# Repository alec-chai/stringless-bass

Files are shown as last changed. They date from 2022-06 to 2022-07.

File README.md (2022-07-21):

# Stringless Bass Project

Lawrence Wilen, Alec Chai, Marley Macarewich

## Summary

This repository contains all of the code, files, and documentation that are necessary for reproducing the stringless basses created during the Summer 2022 Projects to Products CEID Fellowship. Each folder contains necessary files for that iteration.

## Contents

- Working Bass Code
  - Code is labelled using semantic versioning (x.y.z), eg. version 0.2.1. Each y value represents a different physical version of the bass, while an updated z value represents an updated version of the code. For example, both the code labelled v0.4.0 and v0.4.1 would be compatible with the physical bass number v0.4, but v0.4.1 is the more recent version of the code. 
- Deprecated
  - This code is old, outdated, or incompatible with physical designs. It is included here just for documentation, but is not intended to be used seriously for any of the basses.
- Physical Design Files
  - Solidworks, CorelDraw, and exported DXF files necessary for laser cutting the bass prototypes.
- Softpot Calibration Files
  - This folder contains the code and excel sheets necessary to linearize the calibration of the softpots on the basses.
- Pre-alpha
  - This folder contains code that is under construction and uploaded for the purposes of testing.

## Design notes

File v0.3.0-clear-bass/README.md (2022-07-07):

# Version 3: The Brockstar

## Summary

This is the code for the clear bass created from acrylic that was originally intended to be "The Brockstar." This features the large clear "bass-like" cutout.

This is the iteration that was intended to be given to Dean Brock as "The Brockstar", but we delivered Version 2 to him as we had too many technical difficulties to troubleshoot on our actual "Brockstar" iteration.

Code was updated to be a little more legible, however most changes in this code were just deleting extraneous unused variables/code and renaming a number of variables.

## Notable Hardware

- Teensy 3.2
- BNO-055
- Powered by either DC power supply or USB power
- Ethernet connection between bow and bass body

## Changes

- Using the Neopixel library to control LEDs on the entire bow and entire bass body

- Body is cut out of four different layers. From top to bottom: 1/4 inch, 1/4 inch (hollow), 1/2 inch (hollow), 1/4 inch

  - Cavity inside of the bass body is now 3/4 in thick.

## Notes

- The FastLED library has worse performance than the Neopixel library for updating the colors of the neopixel strips in terms of latency and in bugs. In this version of the code, all LED changes are done through the neopixel library.

- This iteration's BNO-055 did not function at all without 4.7 kohm pullup resistors connecting the SDA/SCL lines to ground. Once the pullup resistors were added, the BNO functions quite well. 

- On this iteration, the orientation of the BNO was flipped 180 degrees about the Y-axis, leading to issues with the quaternion code that converts to Euler angles. This was remedied by flipping the sign of the q0prime and q3prime quaternions as:

  - `q0prime = -quat.w();`
  - `q3prime = -quat.z();`

  Another suitable solution was to flip the signs of q1 and q2. 

- The pluck velocity code also needed to change in sign, so the code was updated to ` plucksig = -gyro.z();`

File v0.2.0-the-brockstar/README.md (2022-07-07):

# Version 2: Clear Bass w/ Code Rewrite

## Summary

This is the code for the clear bass created from acrylic. This features the large clear "bass-like" cutout.

This is the iteration that was given to Dean Brock as "The Brockstar", as we had to troubleshoot technical difficulties on our actual "Brockstar" iteration.

Code was updated to be a little more legible, however most changes in this code were just deleting extraneous unused variables/code and renaming a number of variables.

## Notable Hardware

- Teensy 3.2
- BNO-055
- Powered by either DC power supply or USB power
- Ethernet connection between bow and bass body

## Changes

- Added ethernet jack to connect the bass body to the bow
- Added DC power supply
- Cut out of acrylic
- Added Neopixel LEDs to the entire bow and entire bass body
- Renamed L1/L2/L3 to L_nut, L_bridge, and L_between to improve clarity
- LEDs are running using the FastLED library
- Bug fix: Changed the logic of if statements that led to a bowed note being played while in the plucking position.

## Notes

The FastLED library has worse performance than the Neopixel library for updating the colors of the neopixel strips in terms of latency and in bugs. This code is essentially a worse version of the v3-brockstar code, but it is uploaded just for proper documentation.

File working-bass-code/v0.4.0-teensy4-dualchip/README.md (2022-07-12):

# Version 4: unnamed so far

## Summary

This is the code for the 3rd iteration of a clear bass using Teensy 4.0.

Code in this version supports the use of either a FXO-FXA or the BNO by uncommenting certain lines.

## Notable Hardware

- Teensy 4.0 w/ PT8211
- BNO-055 OR FXO-FXA
- Powered by USB power
- Ethernet connection between bow and bass body

## Changes

- Using the Teensy 4.0 instead of 3.2

- Added support for the FXO-FXA motion sensor in place of BNO due to chip shortage

- Body now contains a side port.

## Notes

- None yet

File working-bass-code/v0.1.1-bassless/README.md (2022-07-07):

# Version 1: Bassless

## Summary

Bassless is the copycat iteration of the original wooden basses that we were given in the summer.

Our copycat iteration, Bassless (v1), uses nearly identical code to the original bass that we were given. 

## Notable Hardware

- Teensy 3.2
- BNO-055

## Changes

None - essentially original copy of code

## Notes

This code is roughly the same as the original code, but contains different softpot calibration values and has pins A6 and A7 reversed in terms of which ones map to L1/L3 in the code.

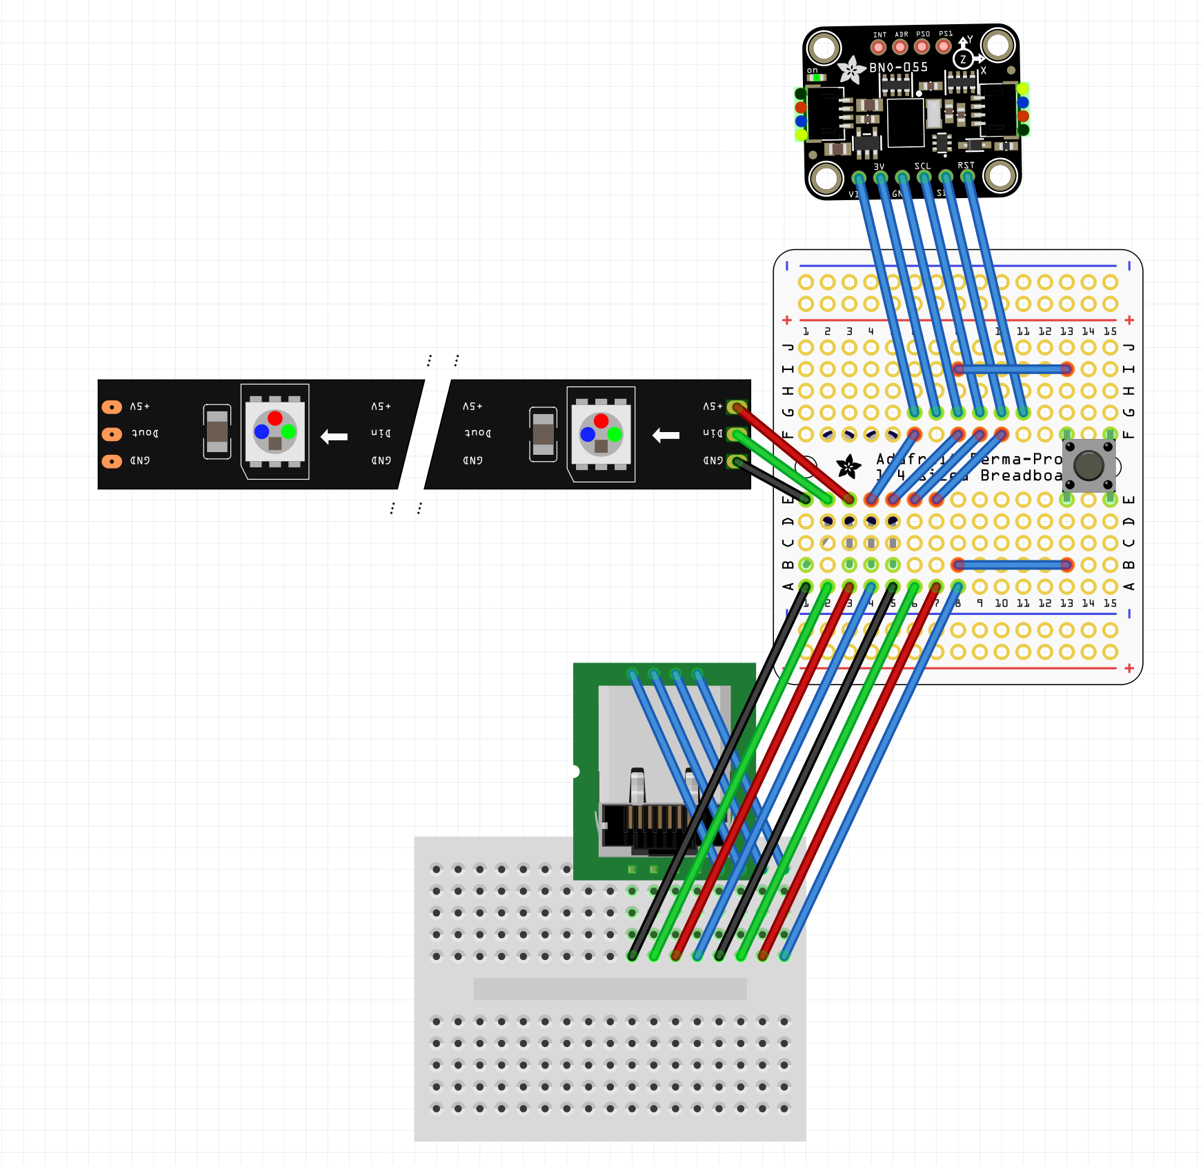
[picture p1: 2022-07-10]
v0.3.0-clear-bass/Fritzing-diagrams/bow-breadboard.png

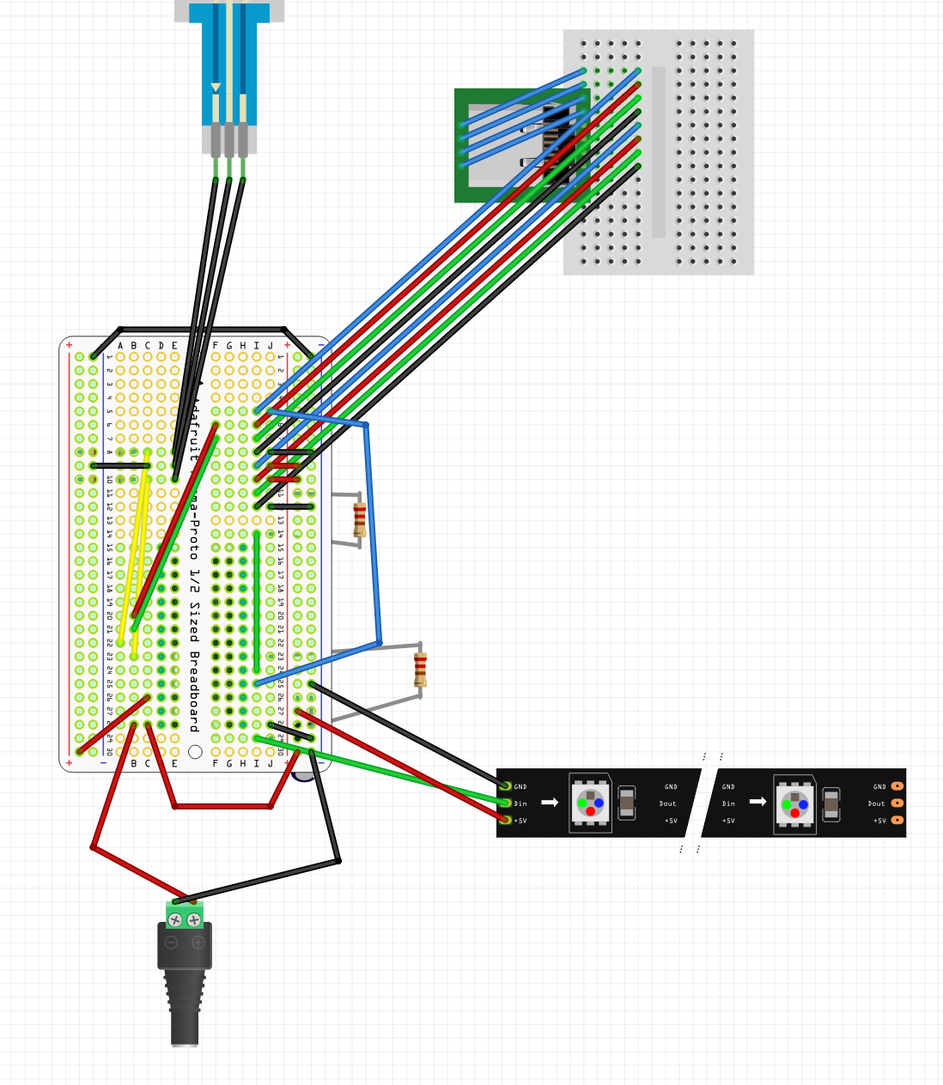
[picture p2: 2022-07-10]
v0.3.0-clear-bass/Fritzing-diagrams/body-breadboard.png

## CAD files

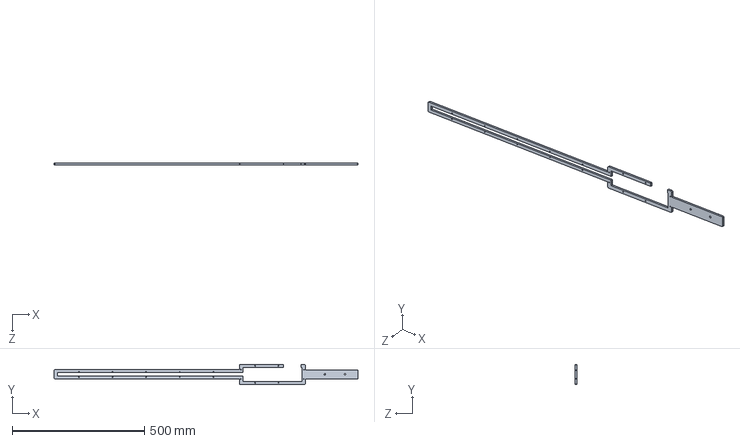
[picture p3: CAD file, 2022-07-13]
physical-design-files/BassMidLayer1.SLDPRT
1148.0 x 75.6 x 6.35 mm

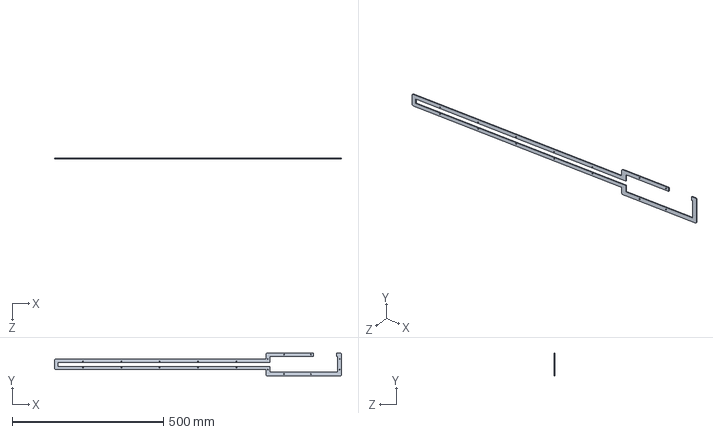
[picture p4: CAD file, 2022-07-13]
physical-design-files/BassMidLayer2.SLDPRT
949.4 x 75.6 x 2.54 mm

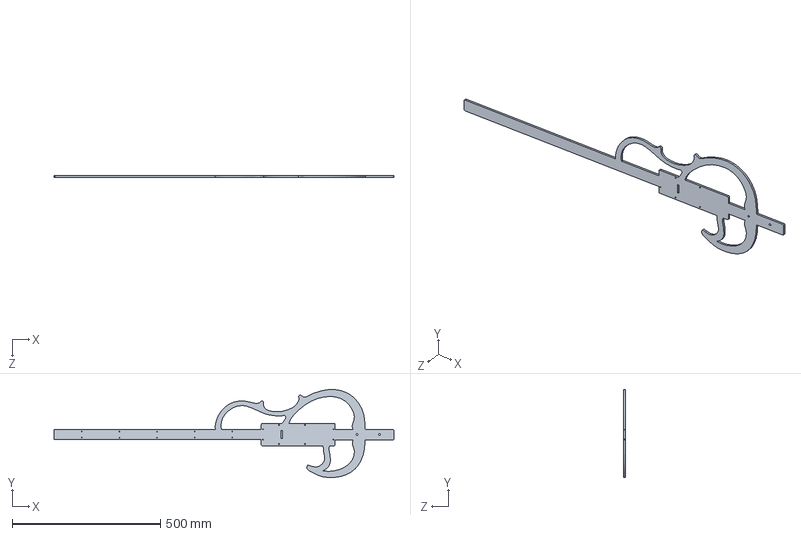
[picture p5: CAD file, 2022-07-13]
physical-design-files/BassTopLayer.SLDPRT
1148.0 x 297.1 x 6.35 mm

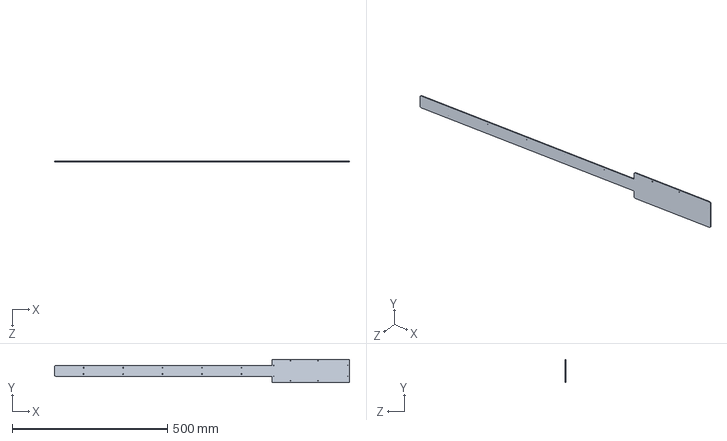
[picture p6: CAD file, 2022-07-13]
physical-design-files/BassBottomLayer.SLDPRT
949.4 x 75.6 x 2.54 mm

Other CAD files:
physical-design-files/BassBottomLayer.DXF
physical-design-files/BassMidLayer1.DXF
physical-design-files/BassMidLayer2.DXF
physical-design-files/BassTopLayer.DXF

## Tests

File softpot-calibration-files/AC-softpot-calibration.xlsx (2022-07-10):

Fret Number | Fret Relative Lstring |  |  | L_bridge softpot | Raw bridge read | Raw nut read | Linear mapping
0 | 1 | 0 | 0 | 75 | open | open | n/a
1 | 0.9438743127 | 2.30115318 | 5.844929077 | 69.15507092 | 2001.63 |  | 0.955719381
2 | 0.8908987181 | 4.473152556 | 11.36180749 | 63.63819251 | 1901.56 |  | 0.8665354259
3 | 0.8408964153 | 6.523246975 | 16.56904732 | 58.43095268 | 1829 |  | 0.8067931187
4 | 0.793700526 | 8.458278435 | 21.48402722 | 53.51597278 | 1732.88 |  | 0.7333017367
5 | 0.7491535384 | 10.28470492 | 26.12315051 | 48.87684949 | 1636.69 |  | 0.665507805
6 | 0.7071067812 | 12.00862197 | 30.50189981 | 44.49810019 | 1551.44 |  | 0.6097085547
7 | 0.6674199271 | 13.63578299 | 34.63488879 | 40.36511121 | 1453.88 |  | 0.5502702375
8 | 0.6299605249 | 15.17161848 | 38.53591093 | 36.46408907 | 1368.56 |  | 0.5017745578
9 | 0.5946035575 | 16.62125414 | 42.21798552 | 32.78201448 | 1265.69 |  | 0.4471912971
10 | 0.5612310242 | 17.98952801 | 45.69340114 | 29.30659886 | 1171.94 |  | 0.4007920494
11 | 0.5297315472 | 19.28100657 | 48.97375668 | 26.02624332 | 1081.06 |  | 0.3585676664
12 | 0.5 | 20.5 | 52.07 | 22.93 | 982.63 |  | 0.3156161972
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

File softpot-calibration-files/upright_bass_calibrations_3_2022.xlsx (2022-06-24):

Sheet: wk bass
0 | 1 | 0 | 0 | 75 | raw |  | this one |  | for longer | tape measure | diff | 0 |  | raw |  | this one | for shorter
1 | 0.9438743127 | 2.30115318 | 5.844929077 | 69.15507092 | 2008 | 334.81 | 0.9616858238 | 0.08901703982 | 69.31124258 | 6.55 | 0.156171653 | 5.844929077 | 2008 | 334.81 | 0.9616858238 | 0.08901703982 | 5.603926786 | 0.2410022908
2 | 0.8908987181 | 4.473152556 | 11.36180749 | 63.63819251 | 1917.81 | 602.19 | 0.8804603822 | 0.1723591151 | 63.48880078 | 12.06687842 | -0.1493917318 | 11.36180749 | 1917.81 | 602.19 | 0.8804603822 | 0.1723591151 | 11.24231987 | 0.1194876252
3 | 0.8408964153 | 6.523246975 | 16.56904732 | 58.43095268 | 1843.31 | 821.5 | 0.8182706009 | 0.2508779966 | 59.02270735 | 17.27411824 | 0.5917546688 | 16.56904732 | 1843.31 | 821.5 | 0.8182706009 | 0.2508779966 | 16.62994957 | -0.06090225059
4 | 0.793700526 | 8.458278435 | 21.48402722 | 53.51597278 | 1741.56 | 1003 | 0.7396918163 | 0.3242806337 | 53.36951608 | 22.18909815 | -0.1464566962 | 21.48402722 | 1741.56 | 1003 | 0.7396918163 | 0.3242806337 | 21.73280862 | -0.2487813951
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

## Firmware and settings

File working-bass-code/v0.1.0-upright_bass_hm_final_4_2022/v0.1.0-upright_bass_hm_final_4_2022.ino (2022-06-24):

/*
 * This version is based off of Konrad's addtions which use an envelope on the bowing action
 * and a different amplitude for the bowing. Also the frequency can change as the bowing is happening
 * There is also a filter acting on the sawtooth waveform which is modified with the theta angle of the bow.
 * There is also a modification to the bowing amplitude with a threshold and power function.
 * 
 * 
 * 
 * 
 */



#include <Wire.h>
#include <Adafruit_Sensor.h>
#include <Adafruit_BNO055.h>
#include <utility/imumaths.h>
#define PI 3.141592653

#include <Audio.h>
#include <SPI.h>
//#include <SD.h>
//#include <SerialFlash.h>
#include <Bounce.h>
#include "AcousticBs_samples.h"

#include <Adafruit_NeoPixel.h>
#define PIN        3 // neopixel pin

// How many NeoPixels are attached to the Arduino?
#define NUMPIXELS 8 // 
Adafruit_NeoPixel pixels(NUMPIXELS, PIN, NEO_GRB + NEO_KHZ800);

// GUItool: begin automatically generated code
AudioSynthWavetable      string1;          //xy=125,106
AudioSynthWaveform       waveform1;      //xy=132,61
AudioEffectEnvelope      envelope1;
AudioMixer4              mixer1;         //xy=353,103
AudioOutputAnalog        dac1;           //xy=506,102
AudioFilterStateVariable filter1;
AudioConnection          patchCord1(string1, 0, mixer1, 1);
AudioConnection          patchCord2(waveform1, 0, filter1, 0);

AudioConnection          patchCord3(filter1, 0, envelope1, 0);

AudioConnection          patchCord4(envelope1, 0, mixer1, 0);
AudioConnection          patchCord5(mixer1, dac1);
// GUItool: end automatically generated code


// Check I2C device address and correct line below (by default address is 0x29 or 0x28)
//                                   id, address
Adafruit_BNO055 bno = Adafruit_BNO055(-1, 0x28);
double long timer0; // variable to store initial time in micros

// the following variables are for the bow velocity
float lin_accelx;
float a_x_board = 0.0; //input
float a_x_board_prev = 0.0;

float a_x_init;

float v_x_board = 0.0; //input
float v_x_board_prev = 0.0;

float delt = 0.01;
//float thresh = 0.03;

//float alpha = .99;
//float beta = 0.99;
//float gammer = 0.98;

float alpha = 1;
float beta = .99;//.997
float gammer = .99;//.995

float out_vx = 0.0; //output
float out_vx_prev = 0.0;

float out_ax = 0.0; //output
float out_ax_prev = 0.0;
// end of bow velocity variables


int bow_angle= 0;
int bow_pos;

float stringfreq;

// the following store and average the analog reads for the two fret positions
float read_raw1;
float read_raw2;
float read_raw1_ave;
float read_raw2_ave;


// the following store the resistances and finger positions
// L_3 is the distance from the finger closest to the bridge to the bridge
// L_1 is the distance from the finger closest to the nut to the nut
// L_2 is the distance between the two fingers
// if there is only one finger, L_2 is the "width" of the finger

float R_1;
float R_2;
float R_3;
float L_1;
float L_2;
float L_3;

int bitnumber = 12;
float resolution = pow(2,bitnumber);
int ave_number = 1;

float string_length;
float base_freq;
float base_freq_discrete;
float low_string_freq = 41.2;//E1

float filter_scale;

  //for the button on bow
Bounce button0 = Bounce(2, 15);
int button0_value;

// the following use the gyro velocity about the z-axis to get the pluck signal
float plucksig;
float plucksig_prev = 0;
float pluck_vel;

int threshL = -150;
int threshH = 40;
int thresh = threshH;

int upflag = 0;
int downflag=0;

int binout = 0;
int binoutprev = 0;

int note_off_flag=0;

int fretnum; //number of half steps up from base note

// these are the euler angles, the quaternions, and the transformed quaternions
float phi;
float theta;
float chi;
float chi0 = 0;
float del_chi;
float q0,q1,q2,q3;
float q0prime, q1prime, q2prime, q3prime;

float scale = 104.14;// this is the length of the open string

bool bowing = false;

void setup(void)
{
  Serial.begin(115200);
  pixels.begin();
  pixels.clear();
  
  AudioMemory(20);

  analogReadResolution(bitnumber);
//  analogReadAveraging(8);

  AudioNoInterrupts(); 
  
  string1.setInstrument(AcousticBs);
  string1.amplitude(1);

  AudioInterrupts();
  mixer1.gain(0, 0.5);//sawtooth waveform for bowing
  mixer1.gain(1, 0.5);//Picked Bs wavetable
 
  delay(500);
  waveform1.begin(WAVEFORM_SAWTOOTH);
  waveform1.amplitude(0.125);
  waveform1.frequency(low_string_freq);

  envelope1.delay(0);
  envelope1.attack(20);  
  envelope1.hold(40);
  envelope1.decay(200);
  envelope1.sustain(1.0);
  envelope1.release(200);

  filter1.resonance(.8);
  filter1.frequency(2000);

//        
  /* Initialise the sensor */
  if (!bno.begin())
  {
    /* There was a problem detecting the BNO055 ... check your connections */
    Serial.print("Ooops, no BNO055 detected ... Check your wiring or I2C ADDR!");
    while (1);
  }
  pinMode(2, INPUT_PULLUP);
//  pinMode(3, OUTPUT); for the four LEDs, not used for hm version
//  pinMode(4, OUTPUT);
//  pinMode(5, OUTPUT);
//  pinMode(6, OUTPUT);
  
  delay(500);
  waveform1.amplitude(0.0);
  imu::Vector<3> linearaccel = bno.getVector(Adafruit_BNO055::VECTOR_LINEARACCEL);
    a_x_init = linearaccel.y();// get initial value for acceleration
  
}

void loop(void)
{
    timer0 = micros();// starts the timer
//    Serial.println(float(micros())/1000.0); // show initial time
//    Serial.println(" ");


    potcalc(); //determines fretted string length L_3, and also L_1, L_2

    bow_angle_calc();  //determines bow_pos and stringfreq, also produces theta, phi, chi
    
  if (L_3 < (3 + (scale - 75.0))){// zeroes bow angle for standing case
    chi0 = chi; 
      }
      
base_freq = stringfreq * scale/L_3;  // for continuous
fretnum = 5* bow_pos + roundup(12.0*log(scale/L_3)/(log(2)));
base_freq_discrete = low_string_freq * pow(2,float(fretnum)/12.0); // for discrete
bow_vel_calc();//determines a bow velocity out_vx
//Serial.println(L_3);
//Serial.println(base_freq_discrete);
Serial.println(fretnum);

waveform1.frequency(base_freq);
string1.setFrequency(base_freq);

if ((phi < 130) && (phi > 50)){// is bow in plucking position?

if (note_off_flag == 0){
  note_off_flag = 1;  
}
pluckcalc();//calculates when a pluck has occurred and plays a plucked note

}

if ((phi < 40) && (phi > -40)){// is bow in bowing position?
if (note_off_flag == 1){

note_off();
note_off_flag = 0;
    
}
bow_action();// bows the string
}

  while((micros()-timer0)<10000){ // this delays for the remainder of the time up to 10ms
  }

}

void bow_action(){

  button0.update();

  if (button0.fallingEdge()) {
    envelope1.sustain(1.0);
    envelope1.noteOn();
    bowing = true;
  }
  if (button0.risingEdge()){
  
 // waveform1.amplitude(0.0);
  envelope1.noteOff();
  bowing = false;
  }
  
  if(bowing) 
  {
   // float amp = abs(out_vx);
    float amp = out_vx * out_vx;

    Serial.println(amp, 8);
    if(amp <= .0003) amp = 0.0;

    amp = pow(amp, 0.3);

    waveform1.amplitude(amp);
  }

  float temp = constrain(theta, -40, 40);
  filter_scale =  40.f * ((temp + 40.) / 80.f) + 6.0;
  filter1.frequency(base_freq * filter_scale);
  
}

void potcalc(){

    read_raw1_ave = 0.0;// some more averaging on the analog reads
    read_raw2_ave = 0.0;  
    for(int i = 0; i <16; i++){      
    read_raw1 = analogRead(A7);
    read_raw2 = analogRead(A6);
    read_raw1_ave = read_raw1_ave + read_raw1;
    read_raw2_ave = read_raw2_ave + read_raw2;
}
    read_raw1_ave = read_raw1_ave/16.0;
    read_raw2_ave = read_raw2_ave/16.0;


    R_1 =  (float(read_raw2_ave)/(resolution - float(read_raw2_ave)));
    R_3 =  (float(read_raw1_ave)/(resolution - float(read_raw1_ave)));
    
if (read_raw1_ave > 0.9*resolution){// this will be true if string is not fretted
L_1 = 0.0;
L_3 = scale;
L_2 = 0.0;
  
}else{

L_3 = (-4.3035 * R_3*R_3 + 75.806 * R_3 - 0.2821) - 75.0 + scale;
// from newest calibration fits 3-28-2022
L_1 =  5.944 * R_1*R_1 + 66.1 * R_1 - 0.3272;
L_2 = scale - (L_1 + L_3);

L_3 = constrain(L_3, 0.0, scale);
}
//    Serial.print(read_raw1_ave);
 //   Serial.print("   ");   
//    Serial.println(read_raw2_ave);

//    Serial.print(L_1);
//    Serial.print("   ");   
//    Serial.print(L_2);
//    Serial.print("   ");       
//    Serial.println(L_3);

}

void bow_angle_calc(){

 imu::Quaternion quat = bno.getQuat();

 q0prime = quat.w();
 q1prime = quat.x();
 q2prime = quat.y();
 q3prime = quat.z(); 

 q0 = (sqrt(2)/2) * q0prime - (sqrt(2)/2) * q3prime;//rotate about z
 q1 = (sqrt(2)/2) * q1prime + (sqrt(2)/2) * q2prime;
 q2 = (sqrt(2)/2) * q2prime - (sqrt(2)/2) * q1prime;
 q3 = (sqrt(2)/2) * q3prime + (sqrt(2)/2) * q0prime;   

// q0 = (sqrt(2)/2) * q0prime - (sqrt(2)/2) * q1prime;//rotate about x
// q1 = (sqrt(2)/2) * q1prime + (sqrt(2)/2) * q0prime;
// q2 = (sqrt(2)/2) * q2prime + (sqrt(2)/2) * q3prime;
// q3 = (sqrt(2)/2) * q3prime - (sqrt(2)/2) * q2prime;   

// q0 = (sqrt(2)/2) * q0prime - (sqrt(2)/2) * q2prime;//rotate about y
// q1 = (sqrt(2)/2) * q1prime - (sqrt(2)/2) * q3prime;
// q2 = (sqrt(2)/2) * q2prime + (sqrt(2)/2) * q0prime;
// q3 = (sqrt(2)/2) * q3prime + (sqrt(2)/2) * q1prime;  

phi = (360/(2*3.141592653))*atan2(2*(q0*q1+q2*q3),1-2*(q1*q1+q2*q2));
theta = (360/(2*3.141592653))*asin(2*(q0*q2-q3*q1));
chi = (360/(2*3.141592653))*atan2(2*(q0*q3+q1*q2),1-2*(q2*q2+q3*q3));
  /* Display the floating point data */

    del_chi = chi - chi0;
if (del_chi < -180){// keep del_chi in the correct range from -180 => 180
  del_chi = del_chi +360;
}

if (del_chi > 180){
  del_chi = del_chi -360;
}
    bow_angle = del_chi;
    bow_angle = constrain(bow_angle, -45,45);
    bow_pos = map(int(bow_angle), -45,45,0,3);// gets the different strings
    bow_pos = constrain(bow_pos,0,3);
    stringfreq = low_string_freq * pow(1.3348,bow_pos);// upright tuned in fourths
//    stringfreq = 130.8;
Serial.println(chi);
Serial.println(bow_pos);
 switch (bow_pos) {
    case 0:    // red
    pixels.clear();
    pixels.setPixelColor(0, pixels.Color(50, 0, 0));
    pixels.setPixelColor(7, pixels.Color(50, 0, 0));
    pixels.show();     
      break;
    case 1:    // yellow
    pixels.clear();
    pixels.setPixelColor(1, pixels.Color(50, 50, 0));
    pixels.setPixelColor(6, pixels.Color(50, 50, 0));
    pixels.show();     
      break;
    case 2:    // green
    pixels.clear();
    pixels.setPixelColor(2, pixels.Color(0, 50, 0));
    pixels.setPixelColor(5, pixels.Color(0, 50, 0));
    pixels.show();     
      break;
    case 3:    // blue
    pixels.clear();
    pixels.setPixelColor(3, pixels.Color(0, 0, 50));
    pixels.setPixelColor(4, pixels.Color(0, 0, 50));
    pixels.show();     
      break; 
  }


}

void pluckcalc(){
  
imu::Vector<3> gyro = bno.getVector(Adafruit_BNO055::VECTOR_GYROSCOPE);  
plucksig = gyro.z();
pluck_vel = 2* (plucksig - plucksig_prev);// factor of 2 just got things in right range
pluck_vel = constrain(pluck_vel, 50,300.0);
//Serial.println(pluck_vel);

  
   if (plucksig <= thresh) {
binout = 0;
thresh = threshH;    
   }

   if (plucksig > thresh) {
binout = 1;
thresh = threshL;  
   }
   
if ( (binoutprev == 0) && (binout == 1)){

upflag = 1;
downflag = 0;
note_on();
  
}else if ( (binoutprev == 1) && (binout == 0)){
upflag = 0;
downflag = 1;
note_off();
 
}else{
upflag = 0;
downflag = 0; 
}
binoutprev = binout;
plucksig_prev = plucksig;

  button0.update();
  if ( button0.fallingEdge() ) {
  
      upflag = 1;
      downflag = 0;
      note_on();
  
  }
  if ( button0.risingEdge() ) {
      upflag = 0;
      downflag = 0; 
  }

}


void bow_vel_calc(){
    imu::Vector<3> linearaccel = bno.getVector(Adafruit_BNO055::VECTOR_LINEARACCEL);
    // this takes a bit of time
    lin_accelx = linearaccel.y();    
    a_x_board = lin_accelx - a_x_init;// subtract iff any initial offset
    out_ax = gammer * out_ax_prev + gammer * ( a_x_board - a_x_board_prev);// high pass accel
    
//    v_x_board = alpha * v_x_board_prev + alpha * 0.5 * (out_ax + out_ax_prev) * delt;
    v_x_board =  v_x_board_prev +  out_ax * delt;// integrate accel to get vel
    out_vx = beta * out_vx_prev + beta * ( v_x_board - v_x_board_prev);//high pass vel


 // Serial.print(bow_pos);
 // Serial.print("  ");
 // Serial.println(out_vx*out_vx*10);
    
  a_x_board_prev = a_x_board;
  out_ax_prev = out_ax;
  v_x_board_prev = v_x_board;
  out_vx_prev = out_vx;
  
}


void note_on(){
mixer1.gain(1, pluck_vel/300.0);
string1.playFrequency(base_freq);

}

void note_off(){
string1.stop();
}



int roundup( float a){

if (a - float(int(a)) > 0){
return int(a)+1;
}else {
return a;
}
  
}

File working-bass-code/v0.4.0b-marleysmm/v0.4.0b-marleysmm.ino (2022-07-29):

/********************************************************

Complete rewrite of bass code from the ground up.

The code should automatically identify whether a BNO or FXO-FXA
sensor is connected and run code accordingly.

To find lines of code that must be changed to switch between 
the Teensy 3.2 and Teensy 4.0 with PT8211 chip, search for "T34"


*********************************************************/

#include "bno055_subs.h"
#include "fxa_fxo_subs.h"

////////////////////////////////////////////////////////////////////////////////////////////////////////////////////

#include <Bounce.h>
#include <Audio.h>
#include <Wire.h>
#include <SPI.h>
#include <SD.h>
#include <SerialFlash.h>
#include "AcousticBs_samples.h"

////////////////////////////////////////////////////////////////////////////////////////////////////////////////////

#include <Adafruit_NeoPixel.h>
#define b_PIN        3 // neopixel pin
#define n_PIN        4 // neopixel pin

// How many NeoPixels are attached to the Arduino?
#define b_NUMPIXELS 10 // 
Adafruit_NeoPixel b_pixels(b_NUMPIXELS, b_PIN, NEO_GRB + NEO_KHZ800);

#define n_NUMPIXELS 108 // 
Adafruit_NeoPixel n_pixels(n_NUMPIXELS, n_PIN, NEO_GRB + NEO_KHZ800);

////////////////////////////////////////////////////////////////////////////////////////////////////////////////////

// GUItool: begin automatically generated code
AudioSynthWaveform       waveform1;      //xy=282,462
AudioSynthWavetable      wavetable1;        //xy=326,512
AudioFilterStateVariable filter1;        //xy=451,415
AudioMixer4              mixer1;         //xy=503,504
AudioEffectEnvelope      envelope1;      //xy=615,408

// T34
AudioOutputPT8211        dac1;
//AudioOutputAnalog        dac1;           //xy=695,600

AudioConnection          patchCord1(waveform1, 0, filter1, 0);
AudioConnection          patchCord2(wavetable1, 0, mixer1, 1);
AudioConnection          patchCord3(filter1, 0, envelope1, 0);
AudioConnection          patchCord4(mixer1, dac1);
AudioConnection          patchCord5(envelope1, 0, mixer1, 0);
// GUItool: end automatically generated code

////////////////////////////////////////////////////////////////////////////////////////////////////////////////////

// Declare global variables
uint8_t mode = 1;
uint8_t bitnumber = 12;
float resolution = pow(2,bitnumber);

uint8_t bow_pos, bow_pos_prev = 0;

////////////////////////////////////////////////////////////////////////////////////////////////////////////////////

// Pot read variables
float bridge_read, nut_read, bridge_ave, nut_ave = 0;
float L_bridge, L_nut, L_between, L_nut_prev = 0;

////////////////////////////////////////////////////////////////////////////////////////////////////////////////////

// Bow velocity variables
float a_x_board = 0.0;
float a_x_board_prev = 0.0;
float a_x_init = 0.0;
float v_x_board = 0.0; //input
float v_x_board_prev = 0.0;
//lin_accelx output by the FXA-FXO and BNO header files
//plucksig output by the FXA-FXO and BNO header files

float beta = .985; // high/low pass filters
float gammer = .97;

float out_vx = 0.0; //output
float out_vx_prev = 0.0; 
float out_ax = 0.0; //output
float out_ax_prev = 0.0;

////////////////////////////////////////////////////////////////////////////////////////////////////////////////////

// Note trigger logic variables
bool bowing = false;
bool bowing_prev = false;
bool button_pressed = false;

////////////////////////////////////////////////////////////////////////////////////////////////////////////////////

// Bass/Cello switching
float open_string_length = 104.14; // Upright bass
float low_string_freq = 41.2; // E1
float string_freq_ratio = 1.3348; // tuned in fourths

//float open_string_length = 75; // Cello
//float low_string_freq = 65.4; // C2
//float string_freq_ratio = 1.5; // tuned in fifths

float playing_freq = 0;

////////////////////////////////////////////////////////////////////////////////////////////////////////////////////

// Angle calc variables
float phi, theta, chi = 0; // Euler Angles
float chi0, delta_chi = 0; // Calibration offset

////////////////////////////////////////////////////////////////////////////////////////////////////////////////////

uint8_t delta_t = 10; // Integration variable, represents time steps in ms

////////////////////////////////////////////////////////////////////////////////////////////////////////////////////

// Pushbutton initialization
Bounce button0 = Bounce(2, 15);

////////////////////////////////////////////////////////////////////////////////////////////////////////////////////

void setup() {
  delay(500); // 0.5 second delay for recovery

  Serial.begin(115200);

  b_pixels.begin(); // Initialize neopixels
  n_pixels.begin();
  b_pixels.clear();
  n_pixels.clear();
  
  AudioMemory(20);
  
  analogReadResolution(bitnumber);

  // Set audio levels
  mixer1.gain(0, 0.5); // sawtooth waveform for bowing
  mixer1.gain(1, 0.5); // plucked bass wavetable

  AudioNoInterrupts(); // Initialize synthesizers
  wavetable1.setInstrument(AcousticBs);
  wavetable1.amplitude(1); 
  waveform1.begin(WAVEFORM_SAWTOOTH);
  waveform1.amplitude(0.0);
  waveform1.frequency(440); // arbitrary starting frequency
  AudioInterrupts();

  envelope1.delay(0);     // envelope attack/release parameters
  envelope1.attack(40);  
  envelope1.hold(40);
  envelope1.decay(200);
  envelope1.sustain(0.6);
  envelope1.release(100);

  filter1.resonance(.8);  // theta angle filter parameters
  filter1.frequency(2000);

  bno055_setup_subs();    // Programatically determine whether BNO/FXO-FXA is connected
  fxa_fxo_setup_subs(); 

  if (using_bno == true) {
    Serial.println("BNO connected!");
    using_fxofxa = false;
  }
  else if (using_fxofxa == true) {
    Serial.println("FXO-FXA Sensor connected!");
    using_bno = false;
  }
  else {
    Serial.print("Could not find sensors. Please connect sensors and restart the instrument.");
    while (1);
  }

  pinMode(2, INPUT_PULLUP); // Initialize button

  waveform1.amplitude(1);
  
  delay(500);
}

////////////////////////////////////////////////////////////////////////////////////////////////////////////////////

void loop() { // low-level implementation of mode selection, more future-proof
  elapsedMillis timer0 = 0;
  
  switch (mode) {
      case 1: // normal bass bowing
      bowingLoop();
        break;
  
      case 2: // softpot touch mode
      touchLoop();
        break;
  }
  
  while (timer0 < delta_t) {} //delay to ensure loop is 10 ms
}

////////////////////////////////////////////////////////////////////////////////////////////////////////////////////
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

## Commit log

2022-06-30 Uploading PCB files
2022-07-06 gerber files
    [bow-stringless-bass 2_contour.gm1, bow-stringless-bass 2_copperBottom.gbl, bow-stringless-bass 2_copperTop.gtl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]
2022-07-07 Added readme's
    [upright_bass_calibrations_3_2022.xlsx]
2022-07-11 addition of dual-chip code
    [AC-softpot-calibration.xlsx, upright_bass_calibrations_3_2022.xlsx]
2022-07-13 Files for Cuts
    [BassBottomLayer.DXF, BassBottomLayer.SLDPRT, BassMidLayer1.DXF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]
2022-07-13 renaming to semantic versioning
    [bass-stringless-bass 2.fzz, bow-stringless-bass 2.fzz]
